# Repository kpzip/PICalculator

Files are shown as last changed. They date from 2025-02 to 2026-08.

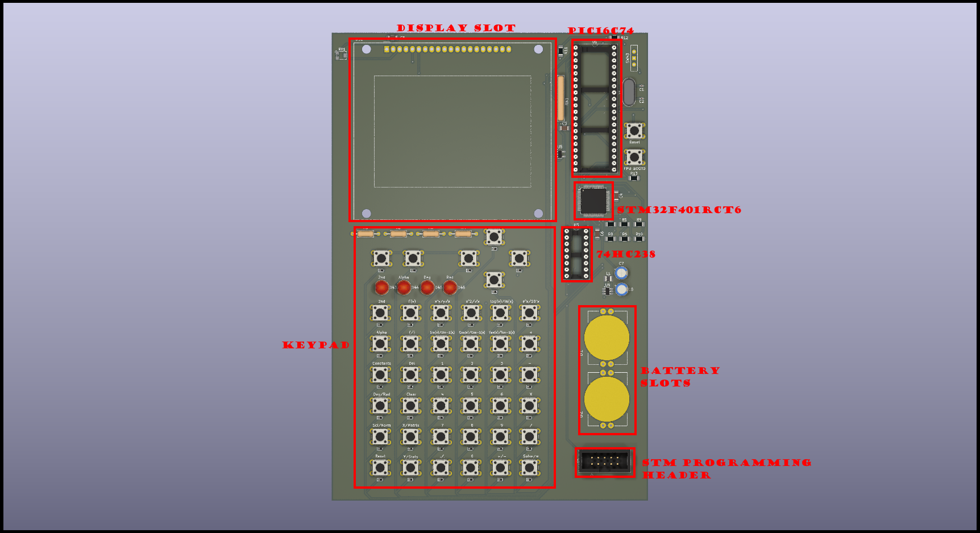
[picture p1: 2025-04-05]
pcb/deliverables/proj.png

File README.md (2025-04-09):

# *Award Winning* PICalculator
calculator made using super ancient PIC μController.

# Past customers have said:
"Fairly risky project that will depend a lot on the development environment. Not clear why 74HC138 will help read the buttons (could probably use SR for same purpose).         need to check what exists in terms of development environment    "This group chose the hardware as they "wanted a challenge". They are definitely one of the smarter groups in my section so I don't have much doubt that they will get it done. 

If you guys do think the hardware is more complex than neccesary, I'm sure they'd be okay with changing out the parts list."    "Are these people really experienced or did they find this project online? If the former, will all group members be able to contribute?

PIC16C74 likely does not have Arduino support. "ARM Cortex M4" is vague and any bare chip will likely only come in an SMD package. Both need a special programmer and special compiler setups. Would need to make a custom PCB or buy a dev board.

Why not just do everything in the M4 since it's vastly more powerful than the PIC?"    Looks like a very challenging project. I am not sure if all group members can contribute if they decide to go with this idea. I think one or two group members are pretty advanced. I feel like it would be hard to provide help to them since most mentors dont have experience with this microcontroller and it requires a different development environment.     Fairly sophisticated, were having issues with some operations outputting the wrong values"

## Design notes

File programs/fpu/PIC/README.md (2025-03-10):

# IO Preprocessor Mode

This code allows the PIC to function as an IO Preprocessor of sorts, leaving the heavy lifting up to the much more capable STM32.
The communication protocol uses SPI and is as follows:

First Byte: (Sent by PIC)
0x00 - PIC is requesting data
0x01 - PIC is sending data

Second Byte:
PIC Send Mode: (Sent by PIC)
0x01 - Key Pressed

STM Send Mode: (Sent by STM)
0x00 - Not Ready
0x01 - No Data
0x02 - Display Command

Third byte:
PIC Send Mode: (Sent by PIC)
value - the key number (0-41)

STM Send Mode: (Sent by STM)
2nd byte was "Not Ready": Resend 2nd Byte, potentially ready this time
2nd Byte was "No Data": No third byte in this case
2nd Byte was "Display Command": bit 0: display register select, bit 1: display read/write (Always 0)

4th byte: Only send if STM is sending a display command:
Display command byte

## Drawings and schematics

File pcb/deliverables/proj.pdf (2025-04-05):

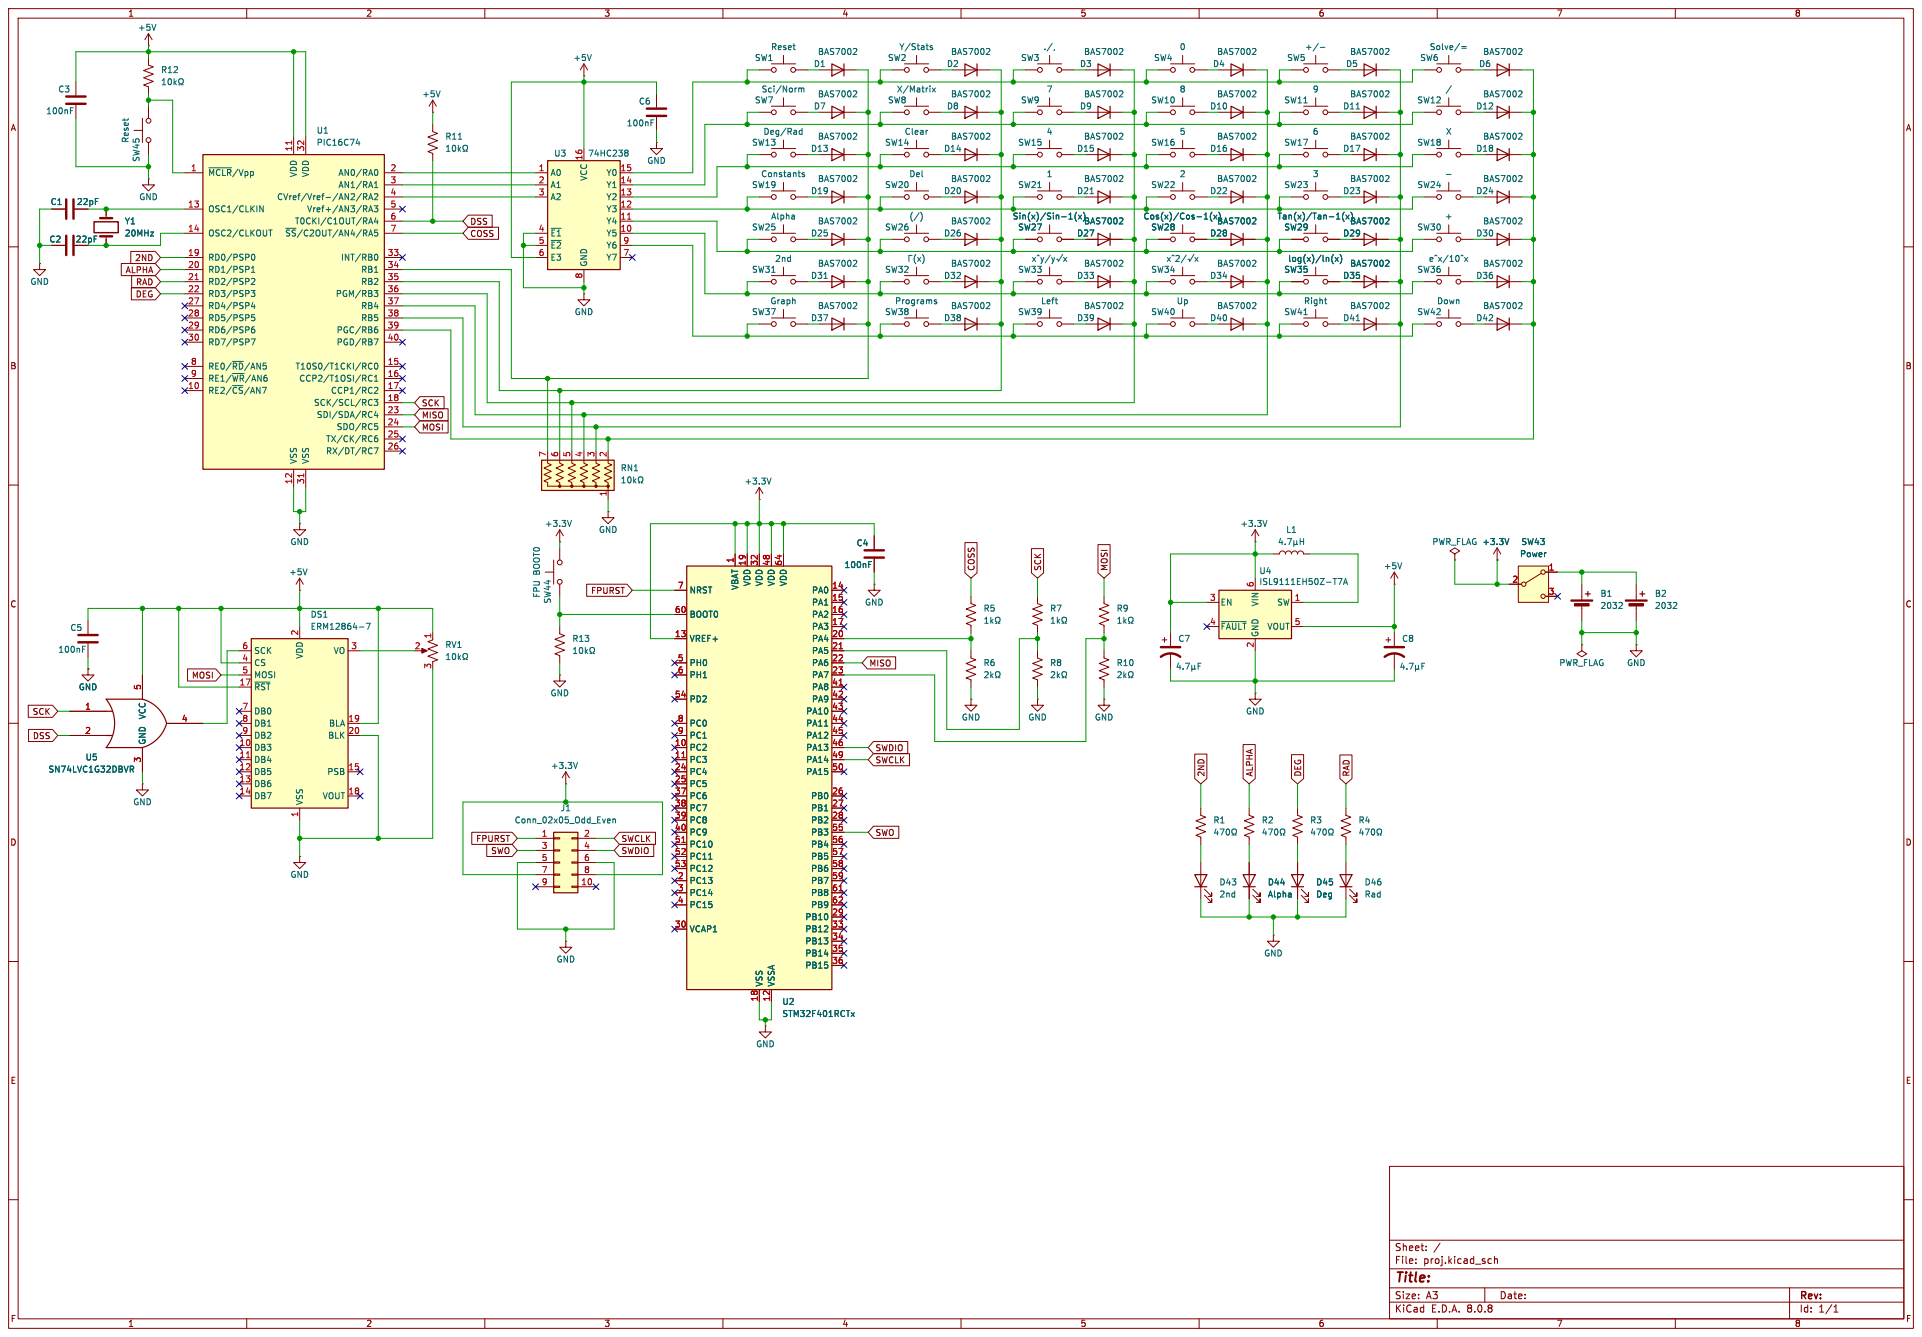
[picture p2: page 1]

SW13 Deg/Rad SW7 Sci/Norm

þÿx^2/"x SW28 Cos(x)/Cos-1(x) D28BAS7002 D33BAS7002 VBAT

log(x)/ln(x) SW29 Tan(x)/Tan-1(x) SW27 Sin(x)/Sin-1(x)

1 PC2 10 PC3 11 VSSA 12 VREF+ 13 PA0 14 PA1 15 PA2 16 PA3 17 VSS 18 VDD 19 PC13 2 PA4 20 PA5 21 PA6 22 PA7 23 PC4 24 PC5 25 PB0 26 PB1 27 PB2 28 PB10 29 PC14 3 VCAP1 30 VDD 32 PB12 33 PB13 34 PB14 35 PB15 36 PC6 37 PC7 38 PC8 39 PC15 4 PC9 40 PA8 41 PA9 42 PA10 43 PA11 44 PA12 45 PA13 46 VDD 48 PA14 49 PH0 5 PA15 50 PC10 51 PC11 52 PC12 53 PD2 54 PB3 55 PB4 56 PB5 57 PB6 58 PB7 59 PH1 6 BOOT0 60 PB8 61 PB9 62 VDD 64 NRST 7 PC0 8 PC1 9 U2STM32F401RCTx

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

2 EN 3 ~{FAULT} 4 VOUT 5 VIN

2 BLK 20 VO 3 CS 4 MOSI 5 SCK 6 DB0 7 DB1 8 DB2 9 DS1 ERM12864-7 D45 Deg D46 Rad GND

1 DB3 10 DB4 11 DB5 12 DB6 13 DB7 14 PSB 15 ~{RST} 17 BLA 19 VDD

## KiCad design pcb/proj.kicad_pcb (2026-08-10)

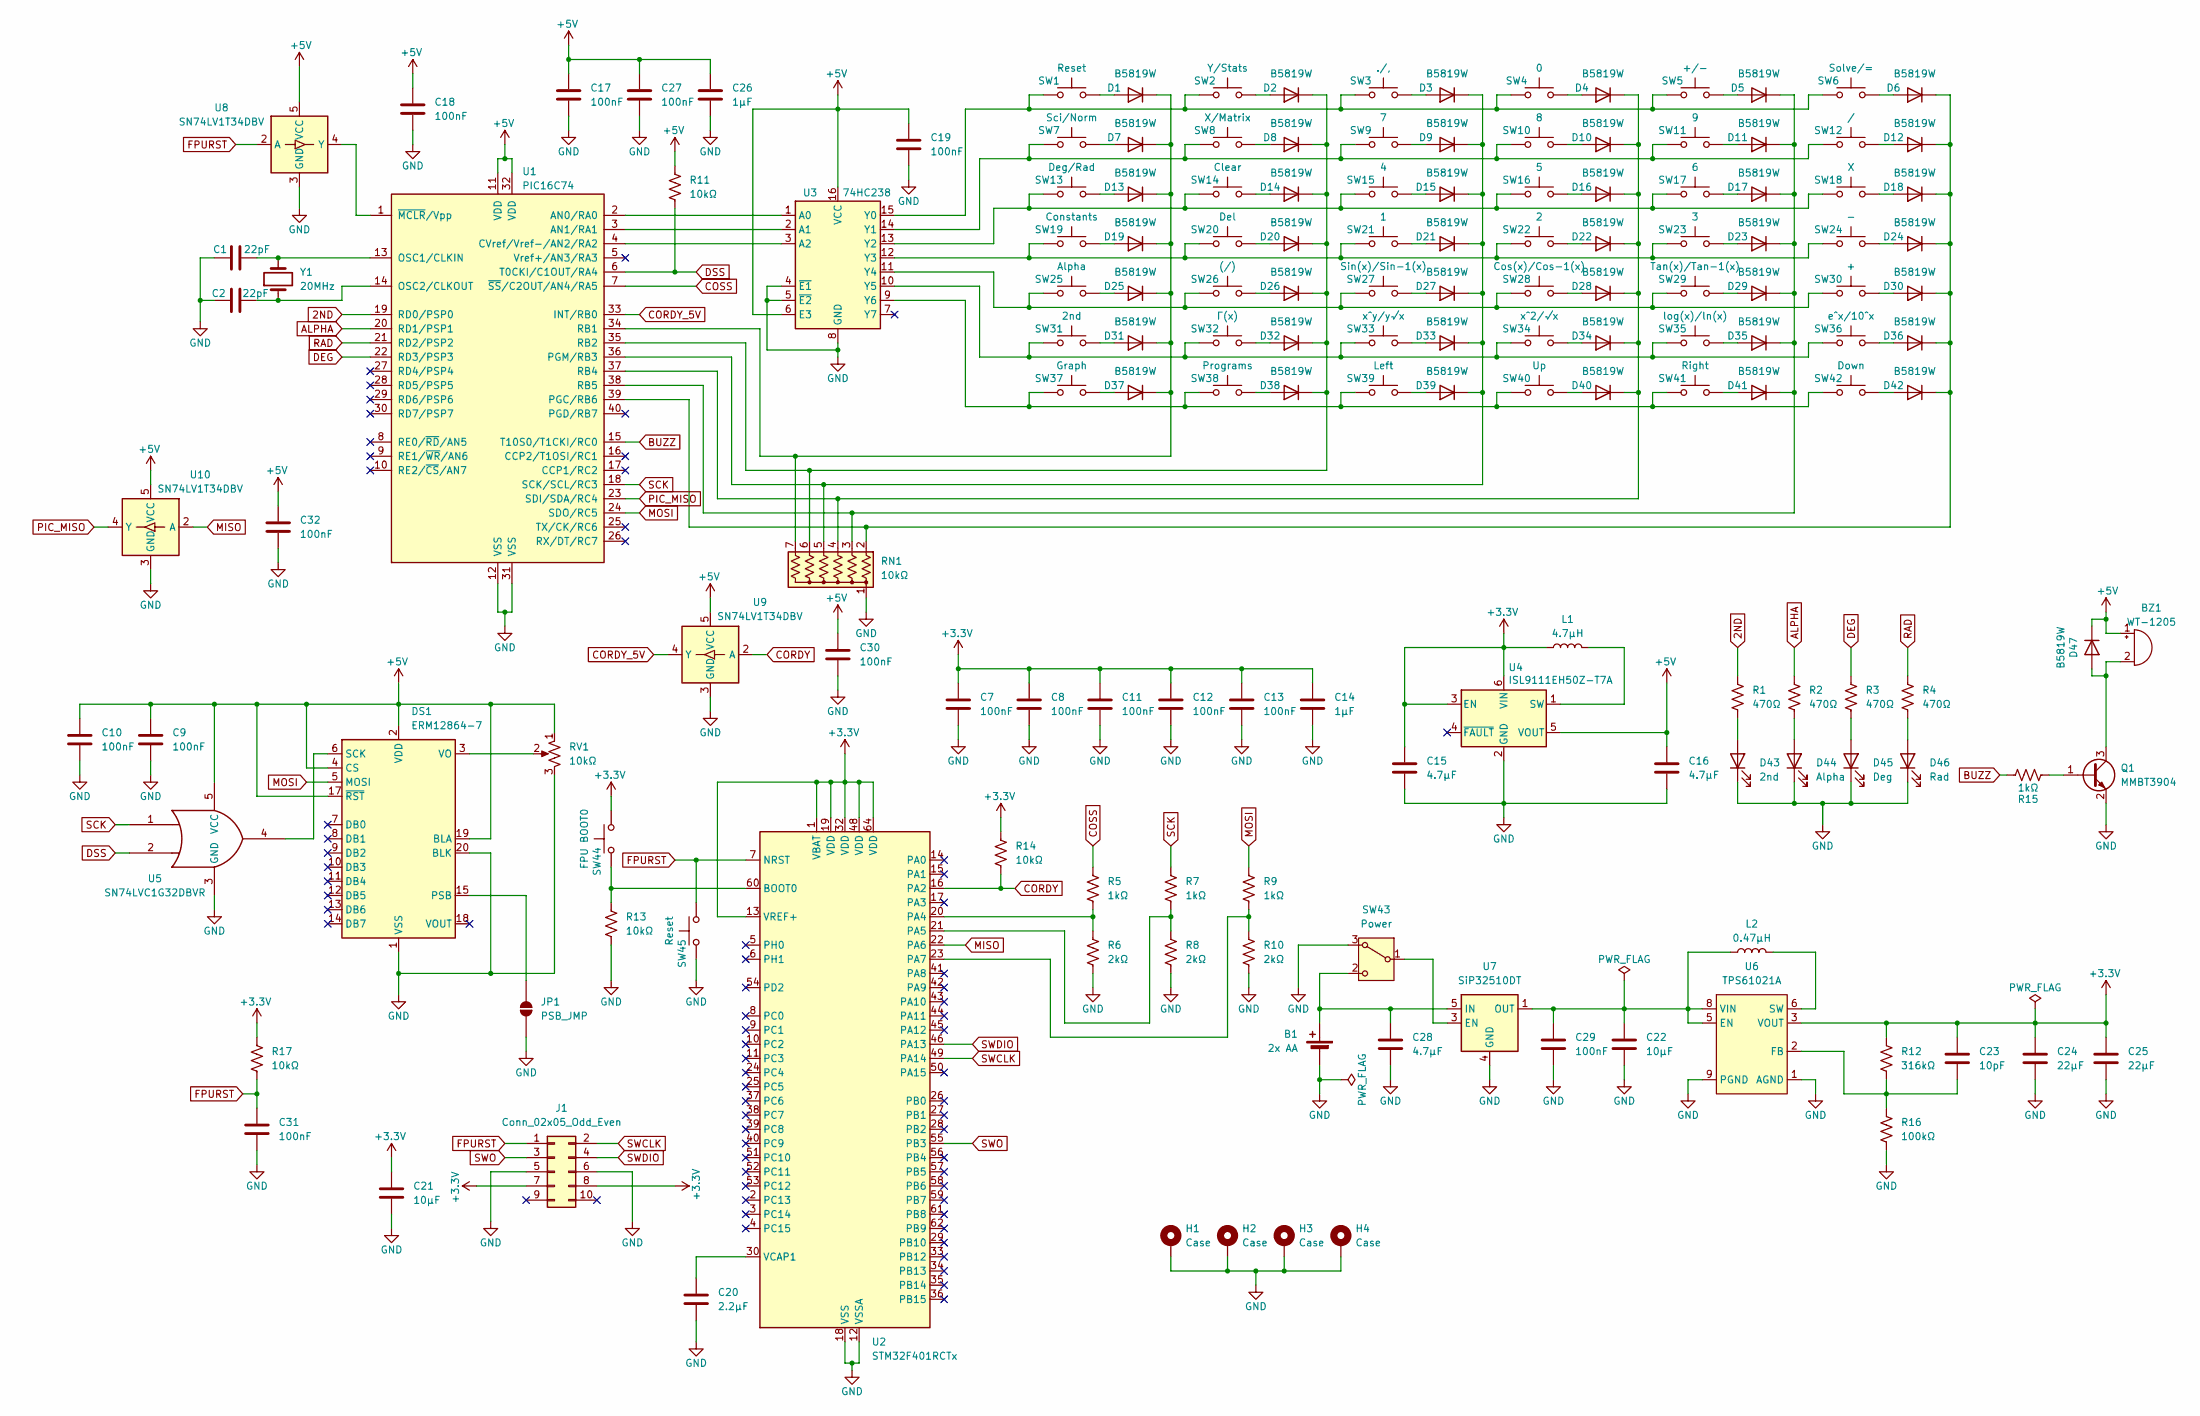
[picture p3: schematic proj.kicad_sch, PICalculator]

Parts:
B1: 2x AA; BatteryHolder_MPD_BC2AAPC_2xAA; Manufacturer Part Number BC2AAPC
BZ1: WT-1205; Buzzer_12x9.5RM7.6; Manufacturer Part Number AI-1223-TWT-5V-5-R
C1, C2: 22pF; C_0603_1608Metric; Manufacturer Part Number CL10C220JB8NNNC
C7, C8, C9, C10, C11, C12, C13, C17, C18, C19, C27, C29, C30, C31, C32: 100nF; C_0402_1005Metric; Manufacturer Part Number CL05B104KO5NNNC
C14, C26: 1μF; C_0603_1608Metric; Manufacturer Part Number CL10A105KB8NNNC
C15, C16, C28: 4.7μF; C_0603_1608Metric; Manufacturer Part Number CL10A475KO8NNNC
C20: 2.2μF; C_0603_1608Metric; Manufacturer Part Number CL10A225KO8NNNC
C21, C22: 10μF; C_0603_1608Metric; Manufacturer Part Number CL10A106MA8NRNC
C23: 10pF; C_0402_1005Metric; Manufacturer Part Number CL05C100JB5NNNC
C24, C25: 22μF; C_0603_1608Metric; Manufacturer Part Number CL10A226MQ8NRNC
D1, D2, D3, D4, D5, D6, D7, D8, D9, D10, D11, D12, D13, D14, D15, D16, D17, D18, D19, D20, D21, D22, D23, D24, D25, D26, D27, D28, D29, D30, D31, D32, D33, D34, D35, D36, D37, D38, D39, D40, D41, D42, D47: B5819W; D_SOD-123F; Manufacturer Part Number B5819W SL
D43: 2nd; LED_D5.0mm; Manufacturer Part Number WP7113ID
D44: Alpha; LED_D5.0mm; Manufacturer Part Number WP7113ID
D45: Deg; LED_D5.0mm; Manufacturer Part Number WP7113ID
D46: Rad; LED_D5.0mm; Manufacturer Part Number WP7113ID
DS1: ERM12864-7; Manufacturer Part Number ERM12864-7
H1, H2, H3, H4: Case; MountingHole_2.2mm_M2_ISO7380_Pad
J1: Conn_02x05_Odd_Even; IDC-Header_2x05_P2.54mm_Vertical; Manufacturer Part Number 302-S101
JP1: PSB_JMP; SolderJumper-2_P1.3mm_Open_RoundedPad1.0x1.5mm
L1: 4.7µH; L_1008_2520Metric_Pad1.43x2.20mm_HandSolder; Manufacturer Part Number FPB252012D-4R7MT0
L2: 0.47µH; L_Coilcraft_XxL4040; Manufacturer Part Number XFL4015-471MEC
Q1: MMBT3904; SOT-23; Manufacturer Part Number MMBT3904(RANGE:100-300)
R1, R2, R3, R4: 470Ω; R_Axial_DIN0207_L6.3mm_D2.5mm_P10.16mm_Horizontal; Manufacturer Part Number CF14JT470R
R5, R7, R9, R15: 1kΩ; R_0603_1608Metric; Manufacturer Part Number 0603WAF1001T5E
R6, R8, R10: 2kΩ; R_0603_1608Metric; Manufacturer Part Number 0603WAF2001T5E
R11, R13, R14, R17: 10kΩ; R_0603_1608Metric; Manufacturer Part Number 0603WAF1002T5E
R12: 316kΩ; R_0402_1005Metric; Manufacturer Part Number 0402WGF3163TCE
R16: 100kΩ; R_0402_1005Metric; Manufacturer Part Number 0402WGF1003TCE
RN1: 10kΩ; R_Array_SIP7; Manufacturer Part Number 4607X-101-103LF
RV1: 10kΩ; Potentiometer_Bourns_TC33X_Vertical; Manufacturer Part Number TC33X-1-103E
SW1, SW45: Reset; SW_PUSH_6mm; Manufacturer Part Number PTS645SL43-2 LFS
SW2: Y/Stats; SW_PUSH_6mm; Manufacturer Part Number PTS645SL43-2 LFS
SW3: ./,; SW_PUSH_6mm; Manufacturer Part Number PTS645SL43-2 LFS
SW4: 0; SW_PUSH_6mm; Manufacturer Part Number PTS645SL43-2 LFS
SW5: +/-; SW_PUSH_6mm; Manufacturer Part Number PTS645SL43-2 LFS
SW6: Solve/=; SW_PUSH_6mm; Manufacturer Part Number PTS645SL43-2 LFS
SW7: Sci/Norm; SW_PUSH_6mm; Manufacturer Part Number PTS645SL43-2 LFS
SW8: X/Matrix; SW_PUSH_6mm; Manufacturer Part Number PTS645SL43-2 LFS
SW9: 7; SW_PUSH_6mm; Manufacturer Part Number PTS645SL43-2 LFS
SW10: 8; SW_PUSH_6mm; Manufacturer Part Number PTS645SL43-2 LFS
SW11: 9; SW_PUSH_6mm; Manufacturer Part Number PTS645SL43-2 LFS
SW12: /; SW_PUSH_6mm; Manufacturer Part Number PTS645SL43-2 LFS
SW13: Deg/Rad; SW_PUSH_6mm; Manufacturer Part Number PTS645SL43-2 LFS
SW14: Clear; SW_PUSH_6mm; Manufacturer Part Number PTS645SL43-2 LFS
SW15: 4; SW_PUSH_6mm; Manufacturer Part Number PTS645SL43-2 LFS
SW16: 5; SW_PUSH_6mm; Manufacturer Part Number PTS645SL43-2 LFS
SW17: 6; SW_PUSH_6mm; Manufacturer Part Number PTS645SL43-2 LFS
SW18: X; SW_PUSH_6mm; Manufacturer Part Number PTS645SL43-2 LFS
SW19: Constants; SW_PUSH_6mm; Manufacturer Part Number PTS645SL43-2 LFS
SW20: Del; SW_PUSH_6mm; Manufacturer Part Number PTS645SL43-2 LFS
SW21: 1; SW_PUSH_6mm; Manufacturer Part Number PTS645SL43-2 LFS
SW22: 2; SW_PUSH_6mm; Manufacturer Part Number PTS645SL43-2 LFS
SW23: 3; SW_PUSH_6mm; Manufacturer Part Number PTS645SL43-2 LFS
SW24: -; SW_PUSH_6mm; Manufacturer Part Number PTS645SL43-2 LFS
SW25: Alpha; SW_PUSH_6mm; Manufacturer Part Number WP7113ID
SW26: (/); SW_PUSH_6mm; Manufacturer Part Number PTS645SL43-2 LFS
SW27: Sin(x)/Sin-1(x); SW_PUSH_6mm; Manufacturer Part Number PTS645SL43-2 LFS
SW28: Cos(x)/Cos-1(x); SW_PUSH_6mm; Manufacturer Part Number PTS645SL43-2 LFS
SW29: Tan(x)/Tan-1(x); SW_PUSH_6mm; Manufacturer Part Number PTS645SL43-2 LFS
SW30: +; SW_PUSH_6mm; Manufacturer Part Number PTS645SL43-2 LFS
SW31: 2nd; SW_PUSH_6mm; Manufacturer Part Number WP7113ID
SW32: Γ(x); SW_PUSH_6mm; Manufacturer Part Number PTS645SL43-2 LFS
SW33: x^y/y√x; SW_PUSH_6mm; Manufacturer Part Number PTS645SL43-2 LFS
SW34: x^2/√x; SW_PUSH_6mm; Manufacturer Part Number PTS645SL43-2 LFS
SW35: log(x)/ln(x); SW_PUSH_6mm; Manufacturer Part Number PTS645SL43-2 LFS
SW36: e^x/10^x; SW_PUSH_6mm; Manufacturer Part Number PTS645SL43-2 LFS
SW37: Graph; SW_PUSH_6mm; Manufacturer Part Number PTS645SL43-2 LFS
SW38: Programs; SW_PUSH_6mm; Manufacturer Part Number PTS645SL43-2 LFS
SW39: Left; SW_PUSH_6mm; Manufacturer Part Number PTS645SL43-2 LFS
SW40: Up; SW_PUSH_6mm; Manufacturer Part Number PTS645SL43-2 LFS
SW41: Right; SW_PUSH_6mm; Manufacturer Part Number PTS645SL43-2 LFS
SW42: Down; SW_PUSH_6mm; Manufacturer Part Number PTS645SL43-2 LFS
SW43: Power; SW_Slide-03_Wuerth-WS-SLTV_10x2.5x6.4_P2.54mm; Manufacturer Part Number EG1218
SW44: FPU BOOT0; SW_PUSH_6mm; Manufacturer Part Number PTS645SL43-2 LFS
U1: PIC16C74; DIP-40_W15.24mm_Socket_LongPads; Manufacturer Part Number PIC16C74
U2: STM32F401RCTx; LQFP-64_10x10mm_P0.5mm; Manufacturer Part Number STM32F401RCT6
U3: 74HC238; SOIC-16_3.9x9.9mm_P1.27mm; Manufacturer Part Number CD74HC238M96
U4: ISL9111EH50Z-T7A; SOT-23-6_Handsoldering
U5: SN74LVC1G32DBVR; SOT-23-5_HandSoldering; Manufacturer Part Number SN74LVC1G32DBVR
U6: TPS61021A; Texas_DSG0008A_WSON-8-1EP_2x2mm_P0.5mm_EP0.9x1.6mm; Manufacturer Part Number TPS61021ADSGR
U7: SiP32510DT; TSOT-23-6; Manufacturer Part Number SIP32510DT-T1-GE3
U8, U9, U10: SN74LV1T34DBV; SOT-23-5; Manufacturer Part Number SN74LV1T34DBVR
Y1: 20MHz; Crystal_HC49-U_Vertical; Manufacturer Part Number AS-20.000-20

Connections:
2ND: R1.1, U1.19 (RD0/PSP0)
+3.3V: C7.1, C8.1, C11.1, C12.1, C13.1, C14.1, C15.1, C21.1, C23.1, C24.1, C25.1, J1.7, J1.8, L1.1, R12.1, R14.1, R17.1, SW44.2, U2.1 (VBAT), U2.13 (VREF+), U2.19 (VDD), U2.32 (VDD), U2.48 (VDD), U2.64 (VDD), U4.3 (EN), U4.6 (VIN), U6.3 (VOUT), U6.4 (VOUT)
+5V: BZ1.1 (+), C9.1, C10.1, C16.1, C17.1, C18.1, C19.1, C26.1, C27.1, C30.1, C32.1, D47.1 (K), DS1.2 (VDD), DS1.4 (CS), DS1.17 (~RST), DS1.19 (BLA), R11.1, RV1.1, U1.11 (VDD), U1.32 (VDD), U3.6 (E3), U3.16 (VCC), U4.5 (VOUT), U5.5 (VCC), U8.5 (VCC), U9.5 (VCC), U10.5 (VCC)
ALPHA: R2.1, U1.20 (RD1/PSP1)
BUZZ: R15.1, U1.15 (T10S0/T1CKI/RC0)
CORDY: R14.2, U2.16 (PA2), U9.2 (A)
CORDY_5V: U1.33 (INT/RB0), U9.4 (Y)
COSS: R5.1, U1.7 (~SS/C2OUT/AN4/RA5)
DEG: R3.1, U1.22 (RD3/PSP3)
DSS: R11.2, U1.6 (T0CKI/C1OUT/RA4), U5.2
FPURST: C31.1, J1.1, R17.2, SW45.2, U2.7 (NRST), U8.2 (A)
GND: B1.2 (-), C1.1, C2.1, C7.2, C8.2, C9.2, C10.2, C11.2, C12.2, C13.2, C14.2, C15.2, C16.2, C17.2, C18.2, C19.2, C20.2, C21.2, C22.2, C24.2, C25.2, C26.2, C27.2, C28.2, C29.2, C30.2, C31.2, C32.2, D43.1 (K), D44.1 (K), D45.1 (K), D46.1 (K), DS1.1 (VSS), DS1.20 (BLK), H1.1 (1_1), H2.1 (1_1), H3.1 (1_1), H4.1 (1_1), J1.5, J1.6, JP1.1 (A), Q1.2 (E), R6.2, R8.2, R10.2, R13.2, R16.2, RN1.1 (common), RV1.3, SW43.3 (A), SW45.1, U1.12 (VSS), U1.31 (VSS), U2.12 (VSSA), U2.18 (VSS), U2.31 (VSS), U2.47 (VSS), U2.63 (VSS), U3.4 (~E1), U3.5 (~E2), U3.8 (GND), U4.2 (GND), U5.3 (GND), U6.1 (AGND), U6.9 (PGND), U7.4 (GND), U8.3 (GND), U9.3 (GND), U10.3 (GND)
MISO: U2.22 (PA6), U10.2 (A)
MOSI: DS1.5 (MOSI), R9.1, U1.24 (SDO/RC5)
unnamed: B1.1 (+), C28.1, SW43.2 (C), U7.5 (IN), U7.6 (IN)
unnamed: BZ1.2 (-), D47.2 (A), Q1.3 (C)
unnamed: D1.2 (A), SW1.2
unnamed: D1.1 (K), D7.1 (K), D13.1 (K), D19.1 (K), D25.1 (K), D31.1 (K), D37.1 (K), RN1.7 (R6), U1.34 (RB1)
unnamed: D2.2 (A), SW2.2
unnamed: D3.2 (A), SW3.2
unnamed: D4.2 (A), SW4.2
unnamed: D5.2 (A), SW5.2
unnamed: D6.2 (A), SW6.2
unnamed: D7.2 (A), SW7.2
unnamed: D8.2 (A), SW8.2
unnamed: D9.2 (A), SW9.2
unnamed: D10.2 (A), SW10.2
unnamed: D4.1 (K), D10.1 (K), D16.1 (K), D22.1 (K), D28.1 (K), D34.1 (K), D40.1 (K), RN1.4 (R3), U1.37 (RB4)
unnamed: D11.2 (A), SW11.2
unnamed: D5.1 (K), D11.1 (K), D17.1 (K), D23.1 (K), D29.1 (K), D35.1 (K), D41.1 (K), RN1.3 (R2), U1.38 (RB5)
unnamed: D12.2 (A), SW12.2
unnamed: D6.1 (K), D12.1 (K), D18.1 (K), D24.1 (K), D30.1 (K), D36.1 (K), D42.1 (K), RN1.2 (R1), U1.39 (PGC/RB6)
unnamed: D13.2 (A), SW13.2
unnamed: D14.2 (A), SW14.2
unnamed: D2.1 (K), D8.1 (K), D14.1 (K), D20.1 (K), D26.1 (K), D32.1 (K), D38.1 (K), RN1.6 (R5), U1.35 (RB2)
unnamed: D15.2 (A), SW15.2
unnamed: D3.1 (K), D9.1 (K), D15.1 (K), D21.1 (K), D27.1 (K), D33.1 (K), D39.1 (K), RN1.5 (R4), U1.36 (PGM/RB3)
unnamed: D16.2 (A), SW16.2
unnamed: D17.2 (A), SW17.2
unnamed: D18.2 (A), SW18.2
unnamed: D19.2 (A), SW19.2
unnamed: D20.2 (A), SW20.2
unnamed: D21.2 (A), SW21.2
unnamed: D22.2 (A), SW22.2
unnamed: D23.2 (A), SW23.2
unnamed: D24.2 (A), SW24.2
unnamed: D25.2 (A), SW25.2
unnamed: D26.2 (A), SW26.2
unnamed: D27.2 (A), SW27.2
unnamed: D28.2 (A), SW28.2
unnamed: D29.2 (A), SW29.2
unnamed: D30.2 (A), SW30.2
unnamed: D31.2 (A), SW31.2
unnamed: D32.2 (A), SW32.2
unnamed: D33.2 (A), SW33.2
unnamed: D34.2 (A), SW34.2
unnamed: D35.2 (A), SW35.2
unnamed: D36.2 (A), SW36.2
unnamed: D37.2 (A), SW37.2
unnamed: D38.2 (A), SW38.2
unnamed: D39.2 (A), SW39.2
unnamed: D40.2 (A), SW40.2
unnamed: D41.2 (A), SW41.2
unnamed: D42.2 (A), SW42.2
unnamed: D43.2 (A), R1.2
unnamed: D44.2 (A), R2.2
unnamed: D45.2 (A), R3.2
unnamed: D46.2 (A), R4.2
unnamed: DS1.15 (PSB), JP1.2 (B)
unnamed: DS1.6 (SCK), U5.4
unnamed: DS1.3 (VO), RV1.2
unnamed: L2.2, U6.6 (SW), U6.7 (SW)
unnamed: Q1.1 (B), R15.2
unnamed: SW43.1 (B), U7.3 (EN)
unnamed: U1.2 (AN0/RA0), U3.1 (A0)
unnamed: U1.3 (AN1/RA1), U3.2 (A1)
unnamed: U1.4 (CVref/Vref-/AN2/RA2), U3.3 (A2)
unnamed: C1.2, U1.13 (OSC1/CLKIN), Y1.2
unnamed: C2.2, U1.14 (OSC2/CLKOUT), Y1.1
unnamed: U1.1 (~MCLR/Vpp), U8.4 (Y)
unnamed: R13.1, SW44.1, U2.60 (BOOT0)
unnamed: R5.2, R6.1, U2.20 (PA4)
unnamed: R7.2, R8.1, U2.21 (PA5)
unnamed: R9.2, R10.1, U2.23 (PA7)
unnamed: C20.1, U2.30 (VCAP1)
unnamed: SW1.1, SW2.1, SW3.1, SW4.1, SW5.1, SW6.1, U3.15 (Y0)
unnamed: SW7.1, SW8.1, SW9.1, SW10.1, SW11.1, SW12.1, U3.14 (Y1)
unnamed: SW13.1, SW14.1, SW15.1, SW16.1, SW17.1, SW18.1, U3.13 (Y2)
unnamed: SW19.1, SW20.1, SW21.1, SW22.1, SW23.1, SW24.1, U3.12 (Y3)
unnamed: SW25.1, SW26.1, SW27.1, SW28.1, SW29.1, SW30.1, U3.11 (Y4)
unnamed: SW31.1, SW32.1, SW33.1, SW34.1, SW35.1, SW36.1, U3.10 (Y5)
unnamed: SW37.1, SW38.1, SW39.1, SW40.1, SW41.1, SW42.1, U3.9 (Y6)
unnamed: L1.2, U4.1 (SW)
unnamed: C22.1, C29.1, L2.1, U6.5 (EN), U6.8 (VIN), U7.1 (OUT), U7.2 (OUT)
unnamed: C23.2, R12.2, R16.1, U6.2 (FB)
PIC_MISO: U1.23 (SDI/SDA/RC4), U10.4 (Y)
RAD: R4.1, U1.21 (RD2/PSP2)
SCK: R7.1, U1.18 (SCK/SCL/RC3), U5.1
SWCLK: J1.2, U2.49 (PA14)
SWDIO: J1.4, U2.46 (PA13)
SWO: J1.3, U2.55 (PB3)

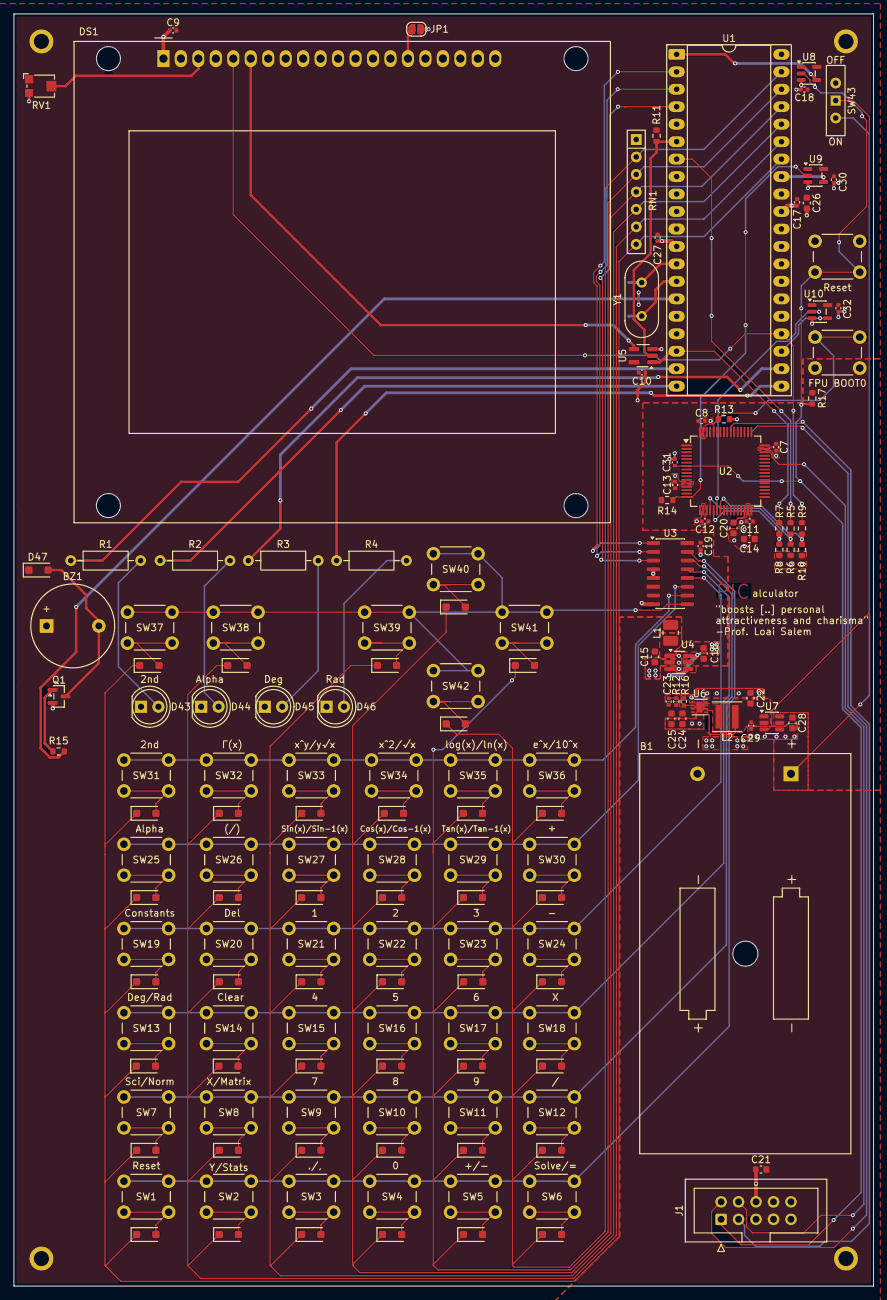
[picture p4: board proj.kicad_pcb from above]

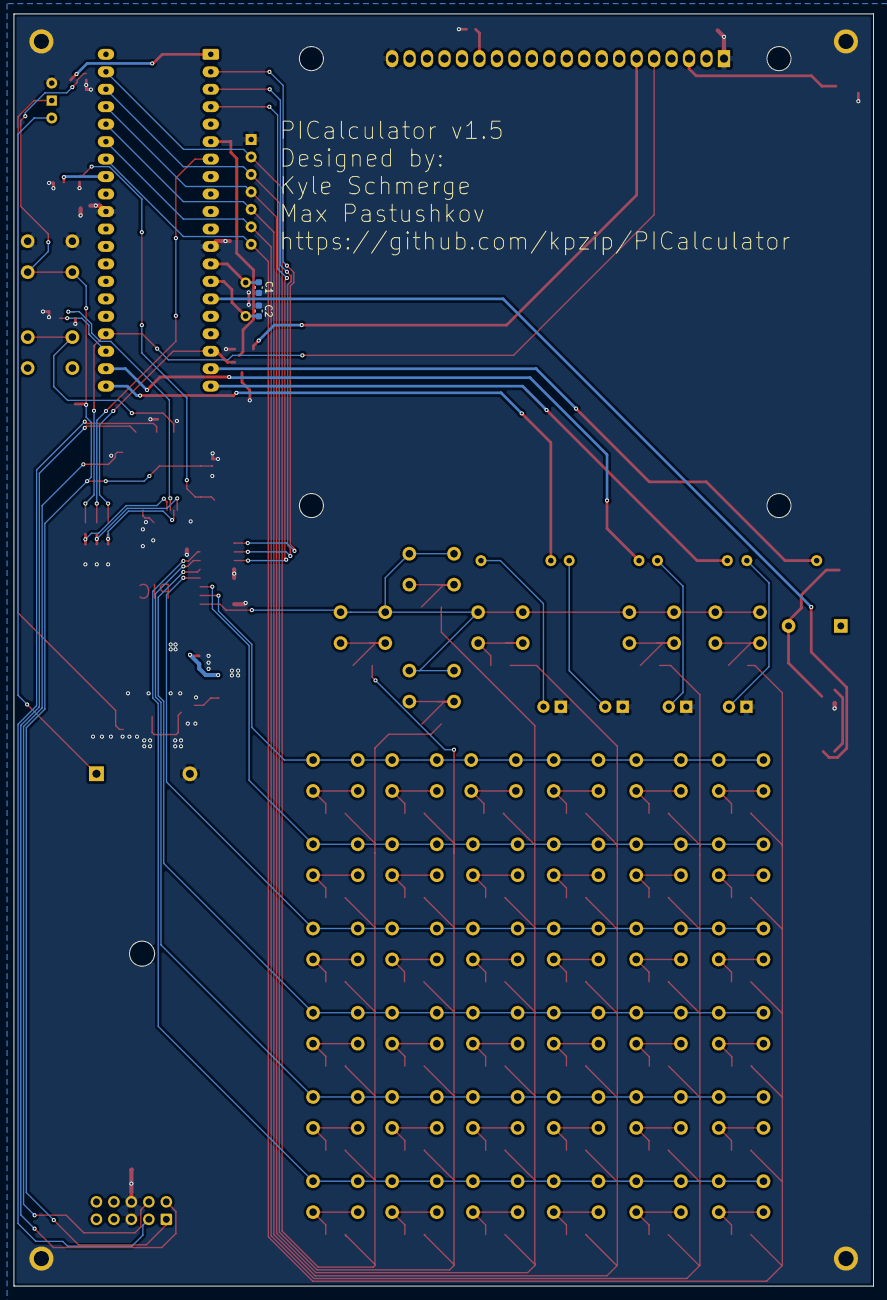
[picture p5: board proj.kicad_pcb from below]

Board: 2 copper layers, 125.0 x 185.0 mm, 162 parts (2 on the bottom side), 101 nets.

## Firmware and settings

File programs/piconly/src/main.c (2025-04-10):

// Comment out for testing
#include <16c74.h>

#include "definitions.h"

// Comment these out when compiling for the pic
//#include "test/test_defs.h"
//#include "test/main.h"
//#include <stdio.h>

// Clock settings
// Comment out for testing
// TODO define these since they are different on our pic
#fuses PLL_DIV_1 PLL_DIV_4
#use delay(clock=20M, RESTART_WDT)

// Comment out to disable Joao mode
#define JOAO_MODE

// Calculator global state
// Bit Vector: each 6 bits represents the y position for each of the 128 x positions.
static uint8_t graph_data_1[48] = { 0 };
static uint8_t graph_data_2[48] = { 0 };

static uint8_t row_counter = 0;
static uint8_t column_counter = 0;
static uint8_t last_button = 255;

// Bit 0: Radians = 0, Degrees = 1; Bit 1: Second mode, 0 = off, Bit2: Alpha mode, 0 = off
static uint8_t status = 0;

// 0: Normal 1: Graph Eq Entry 2: Graph View 3: Joao Viewer
static uint8_t mode = 0;

static char expr_buffer[EXPR_BUF_LEN] = { 0 };
static char graph_eq_buffer[EXPR_BUF_LEN] = { 0 };
static uint8_t expr_write_pointer = 0;
static uint8_t graph_eq_write_pointer = 0;

typedef union {
	uint32_t val;
	uint8_t bytes[4];
} packer;

void set_keyboard_row(uint8_t row) {
	
	// Not sure how necessary all the bit shifting is since the single bit representation is ambiguous
	output_bit(KEYBOARD_0, row & 0x01);
	output_bit(KEYBOARD_1, (row >> 1) & 0x01);
	output_bit(KEYBOARD_2, (row >> 2) & 0x01); 
	
	//output_a(row);
}

void display_command(uint8_t data, uint8_t rs) {
	output_low(DSS);
	spi_write(0xF8 | (rs << 1));
	spi_write(data & 0xF0);
	spi_write((data << 4) & 0xF0);
	output_high(DSS);

	delay_ms(1);
}

void display_data(uint8_t data) {
	output_low(DSS);
	spi_write(data & 0xF0);
	spi_write((data << 4) & 0xF0);
	output_high(DSS);
}

uint16_t pow(uint16_t base, uint16_t exponent) {
	uint16_t ret = 1;
	for (uint8_t i = 0; i < exponent; i++) {
		ret *= base;
	}
	return ret;
}

uint16_t char_to_num(char c) {
	return c - 48;
}

void write_num(uint16_t num) {

    do {
    	expr_buffer[expr_write_pointer++] = (num % 10) + '0';
        num /= 10;
    } while (num > 0);

    uint8_t start = 0;
    uint8_t end = expr_write_pointer - 1;
    while (start < end) {
        char temp = expr_buffer[start];
        expr_buffer[start] = expr_buffer[end];
        expr_buffer[end] = temp;
        start++;
        end--;
    }
}

void enable_normal_mode() {
	// Set mode and clear
	display_command(0x30, 0);
	display_command(0x0E, 0);
	display_command(0x01, 0);

	delay_ms(50);

	// Write the current normal mode expression
	for (uint8_t i = 0; i < expr_write_pointer; i++) {
		display_command(expr_buffer[i], 1);
	}
}

void enable_graph_eq_mode() {
	// Set mode and clear
	display_command(0x30, 0);
	display_command(0x01, 0);

	// Write the function
	display_command('Y', 1);
	display_command('=', 1);
	for (uint8_t i = 0; i < graph_eq_write_pointer; i++) {
		display_command(graph_eq_buffer[i], 1);
	}
}

#separate
void enable_graph_mode() {
	// Set Mode
	
	//display_command(0x01, 0);
	//display_command(0x30, 0);
	display_command(0x0C, 0);
	display_command(0x34, 0);
	display_command(0x36, 0);

	for (uint8_t horizontal_addr = 0; horizontal_addr < 8; horizontal_addr++) {

		// Memory-perf tradeoff. can change this based on which is more important later.
		// Stores the vertical positions of the dots
		uint8_t values[16];
		packer p = {0};

		for (uint8_t group = 0; group < 4; group++) {
			uint8_t index = 3 * (group + 4 * horizontal_addr);
			if (index < 48) {
				p.bytes[0] = graph_data_1[index + 0];
				p.bytes[1] = graph_data_1[index + 1];
				p.bytes[2] = graph_data_1[index + 2];
			} else {
				index -= 48;
				p.bytes[0] = graph_data_2[index + 0];
				p.bytes[1] = graph_data_2[index + 1];
				p.bytes[2] = graph_data_2[index + 2];
			}
			values[group * 4] = p.val & 0b00111111;
			values[group * 4 + 1] = (p.val >> 6) & 0b00111111;
			values[group * 4 + 2] = (p.val >> 12) & 0b00111111;
			values[group * 4 + 3] = (p.val >> 18) & 0b00111111;
		}

		for (uint8_t vertical_addr = 0; vertical_addr < 64; vertical_addr++) {
			uint8_t lsb = 0;
			uint8_t msb = 0;
			uint8_t bit_idx;
			for (bit_idx = 0; bit_idx < 8; bit_idx++) {
				if (values[bit_idx] == vertical_addr) {
					msb |= (0x80 >> bit_idx);
				}
			}
			for (bit_idx = 0; bit_idx < 8; bit_idx++) {
				if (values[bit_idx + 8] == vertical_addr) {
					lsb |= (0x80 >> bit_idx);
				}
			}

			//printf("Vertical Address: %d\n", vertical_addr);
			//printf("Horizontal Address: %d\n", horizontal_addr);

			//printf("LSB: %d\n", lsb);
			//printf("MSB: %d\n", msb);
			
			// X axis
			if (vertical_addr == 32) {
				msb = 0xFF;
				lsb = 0xFF;
			}

			// Set Address
			display_command(0x80 + (vertical_addr >= 32 ? vertical_addr - 32 : vertical_addr), 0);
			display_command(0x80 + (vertical_addr >= 32 ? horizontal_addr + 8 : horizontal_addr), 0);
			
			// Send Data
			display_command(msb, 1);
			display_command(lsb, 1);
		}
	}
}

#ifdef JOAO_MODE
void enable_joao_viewer() {
	
}
#endif

uint16_t parse_from_buffer(char *buf, uint8_t begin, uint8_t end) {
	uint8_t digit_val;
	uint8_t i;	
	uint16_t ret = 0;
	
	for (i = begin; i < end; i++) {
		digit_val = char_to_num(buf[i]);
		if (digit_val == 0xFF) {
			return 0xFFFF;
		}
		ret += pow(10, end - (i + 1)) * digit_val;
	}
	return ret;
}

#separate
void regenerate_graph_data() {
	// form: y=mx+b
	uint8_t m = 0;
	uint8_t b = 0;
	uint8_t i;

	// Can be unionized if need be
	uint8_t pos;
	uint8_t digit_val;
	for (pos = 0; graph_eq_buffer[pos] != 'X'; pos++) {
		if (pos >= graph_eq_write_pointer - 1) {
			goto nox;
		}
	}
	
	m = parse_from_buffer(graph_eq_buffer, 0, pos);
	if (m == 0xFF) {
		goto err;
	}
	pos++;
	
	if (pos < graph_eq_write_pointer - 1 && graph_eq_buffer[pos] == '+') {
		pos++;
		b = parse_from_buffer(graph_eq_buffer, pos, graph_eq_write_pointer);
		if (b == 0xFF) {
			goto err;
		}
	}
	draw:
	;

	uint8_t val;
	uint8_t index;
	packer word;

	word.val = 0;

	// X position loop
	// slow. optimize by calculating one value and going from there
	for (i = 0; i < 128; i++) {
		val = 63 - (((char)i - 63) * m + b + 31);
		if (val > 63) {
			val = 32;
		}
		word.val |= ((uint32_t)val << ((i % 4) * 6));
		// Copy first 3 bytes of word into graphdata
		if (i % 4 == 3) {
			index = (i/4) * 3;
			if (index >= 48) {
				index -= 48;
				graph_data_2[index] = word.bytes[0];
				graph_data_2[index + 1] = word.bytes[1];
				graph_data_2[index + 2] = word.bytes[2];
			} else {
				graph_data_1[index] = word.bytes[0];
				graph_data_1[index + 1] = word.bytes[1];
				graph_data_1[index + 2] = word.bytes[2];
			}
			word.val = 0;
		}
	}
	
	return;
	nox:
	b = parse_from_buffer(graph_eq_buffer, 0, graph_eq_write_pointer);
	if (b == 0xFF) {
		goto err;
	}
	goto draw;
	err:
	graph_eq_buffer[0] = 'e';
	graph_eq_buffer[1] = 'r';
	graph_eq_buffer[2] = 'r';
	graph_eq_write_pointer = 3;
	return;
}

#separate
void simplify_expr() {
	uint8_t i;
	uint8_t first_operator = 0xFF;
	uint8_t second_operator = 0xFF;
	for (i = 0; i < expr_write_pointer; i++) {
		switch(expr_buffer[i]) {
		case '+':
		case '-':
		case '*':
		case '/':
		case '^':
			if (first_operator == 0xFF) {
				first_operator = i;
			} else {
				second_operator = i;
			}
			break;
		default:
			break;
		}
	}

	// No need to simplify if there are no operators!
	// The only way they can be equal is if they are both 0xFF
	if (first_operator == second_operator) {
		return;
	}

	// Maybe make these larger?
	uint16_t first_number = 0;
	uint16_t second_number = 0;
	uint16_t third_number = 0;

	uint8_t digit_val;
	
	first_number = parse_from_buffer(expr_buffer, 0, first_operator);
	if (first_number == 0xFFFF) goto err2;
	if (second_operator != 0xFF) {
		second_number = parse_from_buffer(expr_buffer, first_operator + 1, second_operator);
		if (second_number == 0xFFFF) goto err2;
		third_number = parse_from_buffer(expr_buffer, second_operator + 1, expr_write_pointer);
		if (third_number == 0xFFFF) goto err2;
	}
	else {
		second_number = parse_from_buffer(expr_buffer, first_operator + 1, expr_write_pointer);
		if (second_number == 0xFFFF) goto err2;
	}

	first_operator = expr_buffer[first_operator];
	if (second_operator != 0xFF) second_operator = expr_buffer[second_operator];
	uint16_t result;
	expr_write_pointer = 0;
	if (first_operator == '*') {
		// First operator precedence
		result = first_number * second_number;
		if (second_operator != 0xFF) switch (second_operator) {
		case '+':
			result += third_number;
			break;
		case '-':
			result -= third_number;
			break;
		case '*':
			result *= third_number;
			break;
		case '/':
			//if (third_number == 0) {
			//	goto err2;
			//}
			result /= third_number;
			break;
		case '^':
			result = pow(result, third_number);
			break;
		}

	} else if (first_operator == '/') {
		// First operator precedence
		//if (second_number == 0) {
		//	goto err2;
		//}
		result = first_number / second_number;
		if (second_operator != 0xFF) switch (second_operator) {
		case '+':
			result += third_number;
			break;
		case '-':
			result -= third_number;
			break;
		case '*':
			result *= third_number;
			break;
		case '/':
			//if (third_number == 0) {
			//	goto err2;
			//}
			result /= third_number;
			break;
		case '^':
			result = pow(result, third_number);
			break;
		}
	} else if (first_operator == '^') {
		result = pow(first_number, second_number);
		if (second_operator != 0xFF) switch (second_operator) {
		case '+':
			result += third_number;
			break;
		case '-':
			result -= third_number;
			break;
		case '*':
			result *= third_number;
			break;
		case '/':
			//if (third_number == 0) {
			//	goto err2;
			//}
			result /= third_number;
			break;
		case '^':
			result = pow(result, third_number);
			break;
		}
	} else if (second_operator != 0xFF) {
		// Second operator precedence
		switch (second_operator) {
		case '+':
			result = second_number + third_number;
			break;
		case '-':
			result = second_number - third_number;
			break;
		case '*':
			result = second_number * third_number;
			break;
		case '/':
			//if (third_number == 0) {
			//	goto err2;
			//}
			result = second_number / third_number;
			break;
		case '^':
			result = pow(first_number, second_number);
		}
		switch (first_operator) {
		case '+':
			result += first_number;
			break;
		case '-':
			result = first_number - result;
			break;
		}
	} else {
		switch (first_operator) {
		case '+':
			result = first_number + second_number;
			break;
		case '-':
			result = first_number - second_number;
			break;
		}
	}
	write_num(result);
	return;
err2:
	expr_buffer[0] = 'e';
	expr_buffer[1] = 'r';
	expr_buffer[2] = 'r';
	expr_write_pointer = 3;
	return;

}

void write_character(char c) {
	if (mode == 0) {
		expr_buffer[expr_write_pointer++] = c;
		if (expr_write_pointer != 0) {
			display_command(expr_buffer[expr_write_pointer - 1], 1);
		}

		if (expr_write_pointer >= EXPR_BUF_LEN) {
			//display_command(0x01, 0);
			expr_write_pointer = 0;
		}
	} else if (mode == 1) {
		graph_eq_buffer[graph_eq_write_pointer++] = c;
		if (graph_eq_write_pointer != 0) {
			display_command(graph_eq_buffer[graph_eq_write_pointer - 1], 1);
		}

		if (graph_eq_write_pointer >= EXPR_BUF_LEN) {
			//display_command(0x01, 0);
			graph_eq_write_pointer = 0;
		}
	}
}

#separate
void splash_text() {
	display_command('P', 1);
	display_command('I', 1);
	display_command('C', 1);
	display_command('a', 1);
	display_command('l', 1);
	display_command('c', 1);
	display_command('u', 1);
	display_command('l', 1);
	display_command('a', 1);
	display_command('t', 1);
	display_command('o', 1);
	display_command('r', 1);
	display_command(' ', 1);
	display_command(' ', 1);
	display_command(' ', 1);
	display_command(' ', 1);

	display_command('C', 1);
	display_command('o', 1);
	display_command('p', 1);
	display_command('y', 1);
	display_command('r', 1);
	display_command('i', 1);
	display_command('g', 1);
	display_command('h', 1);
	display_command('t', 1);
	display_command(' ', 1);
	display_command('2', 1);
	display_command('0', 1);
	display_command('2', 1);
	display_command('5', 1);
	display_command(' ', 1);
	display_command(' ', 1);

	display_command('v', 1);
	display_command('1', 1);
	display_command('.', 1);
	display_command('1', 1);
	display_command(' ', 1);
	display_command(' ', 1);
	display_command(' ', 1);
	display_command(' ', 1);
	display_command(' ', 1);
	display_command(' ', 1);
	display_command(' ', 1);
	display_command(' ', 1);
	display_command(' ', 1);
	display_command(' ', 1);
	display_command(' ', 1);
	display_command(' ', 1);
}

void main() {
	// Initialize Pins

	set_tris_a(0x00);
	set_tris_b(0xFF);
	set_tris_d(0x00);
	set_tris_e(0x00);

	// Chip Select pins
	// Award winning unimplemented Chip Select!!!
	output_high(DSS);
	output_high(COSS);

	disable_interrupts(GLOBAL);

	// Keyboard matrix pins
	output_low(KEYBOARD_0);
	output_low(KEYBOARD_1);
	output_low(KEYBOARD_2);

	// Init the SPI bus
	setup_spi(SPI_MASTER | SPI_SCK_IDLE_HIGH | SPI_CLK_DIV_64);

	// Initialize display
	delay_ms(1);
	display_command(0x30, 0); // Function set: 8 bit interface, basic instruction set
	// display_command(0x08, 0); // Display status: Everything off
	// display_command(0x10, 0); // Cursor: Move left (?)
	display_command(0x0E, 0); // Display status: Display, cursor, and blink on
	display_command(0x01, 0); // Clear
	display_command(0x06, 0); // Make cursor move right
	// display_command(0x80, 0); // Home the cursor (unneccesary)

	// Powerup sequence
	output_high(SECOND_LED);
	output_high(ALPHA_LED);
	output_high(RADIANS_LED);
	output_high(DEGREES_LED);

	// Write PICalculator text
	splash_text();

#ifdef JOAO_MODE
	display_command('J', 1);
	display_command('o', 1);
	display_command('a', 1);
	display_command('o', 1);
	display_command(' ', 1);
	display_command('E', 1);
	display_command('d', 1);
	display_command('i', 1);
	display_command('t', 1);
	display_command('i', 1);
	display_command('o', 1);
	display_command('n', 1);
	display_command(' ', 1);
	display_command(' ', 1);
	display_command(' ', 1);
	display_command(' ', 1);
#endif

	delay_ms(2000);

	output_low(SECOND_LED);
	output_low(ALPHA_LED);
	output_low(RADIANS_LED);
	output_low(DEGREES_LED);
	display_command(0x01, 0);

	// Sync LED
	output_high(RADIANS_LED);

	// Main calculator loop
	while (TRUE) {
		// Check for input: scan across different button ranks and determine the button pressed if any
		uint8_t any_button_pressed = 0;
		for (row_counter = 0; row_counter < 7; row_counter++) {
			set_keyboard_row(row_counter);
			for (column_counter = 0; column_counter < 6; column_counter++) {
				if (input(KEYBOARD_IN + column_counter)) {
					uint8_t button_id = column_counter + row_counter * 6;
					if (last_button != button_id) {
						last_button = button_id;
						any_button_pressed = 1;
					} else {
						any_button_pressed = 2;
					}
				}
			}
		}
		if (any_button_pressed == 2) {
			// Do Nothing since we just re-registered the last button press
		} else if (any_button_pressed == 1) {
			uint8_t second = (status >> 1) & 1;
			uint8_t alpha = (status >> 2) & 1;
			// Cases are responsible for updating the display
			switch(last_button) {
			// Reset
			case 0:
				expr_write_pointer = 0;
				display_command(0x01, 0); // Clear display
				break;
			// Gamma
			case 31:
				output_low(COSS);
				spi_write(status);
				delay_ms(10);
				status = spi_read(0x00);
				second = (status >> 1) & 1;
				alpha = (status >> 2) & 1;
				uint8_t degrad = status & 1;
				output_bit(SECOND_LED, second);
				output_bit(ALPHA_LED, alpha);
				output_bit(RADIANS_LED, degrad ^ 1);
				output_bit(DEGREES_LED, degrad);
				output_high(COSS);
				break;
			////////////
			// Numpad //
			////////////
			case 3:
				// Numpad 0
				write_character('0');
				break;
			case 8:
				// Numpad 7
				write_character('7');
				break;
			case 9:
				// Numpad 8
				write_character('8');
				break;
			case 10:
				// Numpad 9
				write_character('9');
				break;
			case 14:
				// Numpad 4
				write_character('4');
				break;
			case 15:
				// Numpad 5
				write_character('5');
				break;
			case 16:
				// Numpad 6
				write_character('6');
				break;
			case 20:
				// Numpad 1
				write_character('1');
				break;
			case 21:
				// Numpad 2
				write_character('2');
				break;
			case 22:
				// Numpad 3
				write_character('3');
				break;
			/////////////////////////
			// 2nd, Alpha, Deg/Rad //
			/////////////////////////
			case 12:
				// Deg/Rad toggle
				if (second == 0) {
					status |= 1;
					output_high(DEGREES_LED);
					output_low(RADIANS_LED);
				} else {
					status &= (~1);
					output_low(DEGREES_LED);
					output_high(RADIANS_LED);
				}
				break;
			case 24:
				// Alpha
				if (alpha == 0) {
					status |= (1 << 2);
					output_high(ALPHA_LED);
				} else {
					status &= (~(1 << 2));
					output_low(ALPHA_LED);
				}
				break;
			case 30:
				// 2nd
				if (second == 0) {
					status |= (1 << 1);
					output_high(SECOND_LED);
				} else {
					status &= (~(1 << 1));
					output_low(SECOND_LED);
				}
				break;
			/////////////////
			// +, -, *, /  //
			/////////////////
			case 29:
				// Add sign
				write_character('+');
				break;
			case 23:
				// Subtract sign
				write_character('-');
				break;
			case 17:
				// Multiplication sign
				write_character('*');
				break;
			case 11:
				// Divide sign
				write_character('/');
				break;
			/////////////////
			//  variables  //
			/////////////////
			case 7:
				write_character('X');
				break;
			/// Other stuff
			case 36:
				// Graph mode
				switch(mode) {
				case 0:
					// Normal Mode
					// Set to Graph eq mode
					enable_graph_eq_mode();
					mode = 1;
					break;
				case 1:
					// Graph Equation Entry
					// Graph the equation and go into the graph view
					regenerate_graph_data();
					enable_graph_mode();
					mode = 2;
					break;
				case 2:
					// Graph View
					// Set back to normal mode
					enable_normal_mode();
					mode = 0;
					break;
#ifdef JOAO_MODE
				case 3:
					// Joao Mode Behavior
					break;
#endif
				default:
					// Shouldnt end up here
					break;
				}

				// TODO
				break;
			case 5:
				// Eval / equals
				if (mode == 0) {
					simplify_expr();
					enable_normal_mode();
				}
				break;
			default:
				// TODO other cases
				break;
			}
		} else {
			last_button = 255;
		}
	}
}

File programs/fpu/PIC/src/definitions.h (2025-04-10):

/*
 * definitions.h
 *
 *  Created on: Feb 24, 2025
 *      Author: kpzip
 */

#ifndef SRC_DEFINITIONS_H_
#define SRC_DEFINITIONS_H_

typedef unsigned char uint8_t;
typedef long uint16_t;
typedef long long uint32_t;

#define EXPR_BUF_LEN 16

#define DSS PIN_A4
#define COSS PIN_A5

#define KEYBOARD_0 PIN_A0
#define KEYBOARD_1 PIN_A1
#define KEYBOARD_2 PIN_A2

#define KEYBOARD_IN PIN_B1

#define SECOND_LED PIN_D0
#define ALPHA_LED PIN_D1
#define RADIANS_LED PIN_D2
#define DEGREES_LED PIN_D3

#define CO_READY PIN_C1


#endif /* SRC_DEFINITIONS_H_ */

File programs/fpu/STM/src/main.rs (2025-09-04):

#![feature(raw_ref_op)]
#![allow(clippy::empty_loop)]
#![no_main]
#![no_std]

mod gui;
mod keymaps;
mod util;

extern crate alloc;
extern crate panic_halt;

use alloc::string::ToString;
use core::ops::{Deref, DerefMut};

use crate::hal::{pac, prelude::*};
use cortex_m_rt::entry;
use hal::gpio::alt::spi1::Nss;
use hal::spi::{Mode, Phase, Polarity};
use rtt_target::{rprintln, rtt_init_print};
use stm32f4xx_hal as hal;
use gui::{CalculatorMenu, CalculatorState, sci_error, sci_mode};
use embedded_alloc::LlffHeap as Heap;
use stm32f4xx_hal::flash::{FlashExt, LockedFlash};

#[global_allocator]
static HEAP: Heap = Heap::empty();

#[entry]
fn main() -> ! {
    rtt_init_print!();

    // Initialize the allocator BEFORE you use it
    {
        use core::mem::MaybeUninit;
        const HEAP_SIZE: usize = 1024 * 4;
        static mut HEAP_MEM: [MaybeUninit<u8>; HEAP_SIZE] = [MaybeUninit::uninit(); HEAP_SIZE];
        unsafe { HEAP.init(&raw mut HEAP_MEM as usize, HEAP_SIZE) }
    }

    let dp = pac::Peripherals::take().unwrap();
    let cp = cortex_m::Peripherals::take().unwrap();

    // let flash = dp.FLASH;
    // flash.acr().modify(|_r, w| unsafe {
    //     w.latency().bits(0b1111)
    // });

    let gpioa = dp.GPIOA.split();

    // Set up the system clock. We want to run at 48MHz for this one.
    let rcc = dp.RCC.constrain();
    let clocks = rcc.cfgr.sysclk(48.MHz()).freeze();



    // Create a delay abstraction based on SysTick
    let mut delay = cp.SYST.delay(&clocks);

    let mut ready = gpioa.pa2.into_push_pull_output();
    ready.set_low();

    let sck = gpioa.pa5;
    let mut miso = gpioa.pa6;
    let mosi = gpioa.pa7;
    let nss = gpioa.pa4;

    let mut spi = dp.SPI1.spi_slave(
        (sck, miso, mosi, Some(Nss::from(nss))),
        Mode {
            phase: Phase::CaptureOnSecondTransition,
            polarity: Polarity::IdleHigh,
        },
    );

    // Buffer for reading in SPI data
    let mut data: [u8; 2] = [0; 2];

    // Calc State
    let mut calc_state = CalculatorState::new();

    loop {

        match spi.read(&mut data) {
            Ok(()) => {
                rprintln!("Received data: {:02X?}", data);
                // Key press code
                if data[0] == 1 {
                    let key_id = data[1];
                    gui::handle_button_press(key_id, &mut calc_state);
                    gui::update_gui(&mut calc_state, &mut spi, &mut ready);
                } else {
                    rprintln!("Error Unknown Request: {:02X?}", data);
                }
            }
            Err(e) => {
                rprintln!("Error: {:?}", e);
            }
        }
    }
}

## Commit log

2025-01-19 switch to C++
2025-03-02 pcb work
    [proj.kicad_pcb, proj.kicad_sch]
2025-03-06 minor updates
    [proj.kicad_pcb, proj.kicad_sch]
2025-03-11 archive v1.1
    [proj.kicad_pcb, proj.kicad_sch]
2025-04-07 v 1.2
    [proj.kicad_pcb, proj.kicad_sch]
2025-04-15 update schematics + add CO RDY trace
    [proj.kicad_pcb, proj.kicad_sch]
2025-04-19 add buzzer and join resets
    [proj.kicad_pcb, proj.kicad_sch]
2025-04-21 fix bugs with passthrough mode
    [main.c]
2025-05-29 archive 1.3
    [proj.kicad_pcb, proj.kicad_sch]
2025-05-29 false alarm
    [proj.kicad_pcb, proj.kicad_sch]
2025-06-02 add titles
    [proj.kicad_sch]
2025-06-22 stupid nub
    [proj.kicad_pcb]
2025-07-02 debug spi
2026-07-23 work on v1.5
    [proj.kicad_pcb, proj.kicad_sch]
2026-07-30 BOM improvements
    [proj.kicad_pcb, proj.kicad_sch]
2026-07-31 add famous quote
    [proj.kicad_pcb]
2026-08-09 hide stuff
    [proj.kicad_sch]
2026-08-10 final ish fixes
    [proj.kicad_pcb, proj.kicad_sch]
